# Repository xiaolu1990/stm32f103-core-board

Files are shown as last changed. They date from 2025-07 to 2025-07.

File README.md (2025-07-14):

## What is this?

This is a customized development board for STM32F103C8T6 Microcontroller. It can be powered and communicated to PC using the USB-C cable in USB 2.0 highspeed. The small size also allows to fit nicely either on a breadboard or as a module on your pcb.

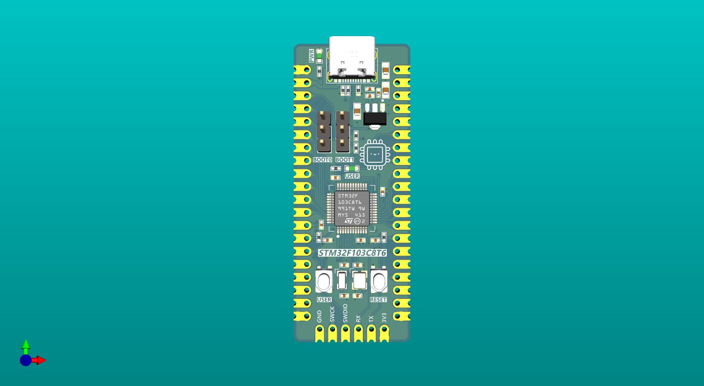
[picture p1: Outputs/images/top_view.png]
top view

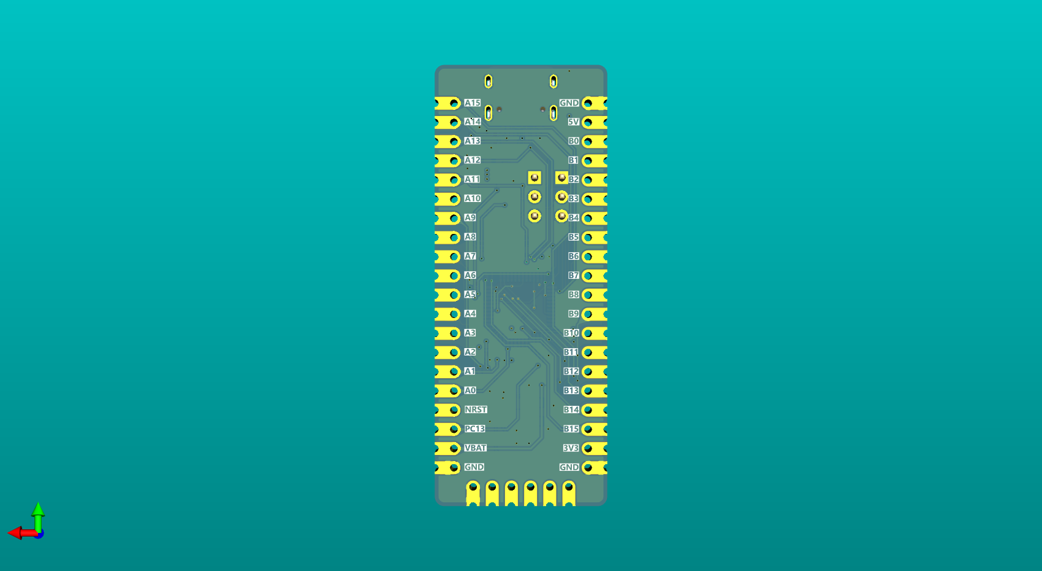
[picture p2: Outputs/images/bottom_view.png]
bottom view


## How to open the project?

Use Kicad 9.0+ versions to open the project.

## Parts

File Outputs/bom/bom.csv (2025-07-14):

Reference | Qty | Value | MPN | Manufacturer | Description
C2,C4,C7 | 3 | 4.7uF | GRM188R61E475KE11D | Murata Electronics | CAP CER 4.7UF 25V X5R 0603
C3,C5,C6,C13,C14,C15,C16,C17,C18 | 9 | 0.1uF | GRM155R71C104KA88J | Murata Electronics | CAP CER 0.1UF 16V X7R 0402
C9,C10,C11,C12 | 4 | 20pF | GRM1555C1H200JA01D | Murata Electronics | CAP CER 20PF 50V C0G/NP0 0402
CN1 | 1 | USB4105-GF-A | USB4105-GF-A | GCT | USB2.0 TYP C
J1,J2 | 2 | Conn_01x03_Pin |  |  | Generic connector, single row, 01x03, script generated
J3 | 1 | SWD |  |  | Generic connector, single row, 01x06, script generated
J4,J5 | 2 | Conn_01x20 |  |  | Generic connector, single row, 01x20, script generated (kicad-library-utils/schlib/autogen/connector/)
LED1 | 1 | 150060VS75000 | 150060VS75000 | Würth Elektronik | LED GREEN CLEAR 0603 SMD
LED2 | 1 | 150060YS75000 | 150060YS75000 | Würth Elektronik | LED YELLOW CLEAR 0603 SMD
R1 | 1 | 1K5 | RC0402JR-071K5L | YAGEO | RES 1.5K OHM 5% 1/16W 0402
R2,R8 | 2 | 1K | RC0402JR-071KL | YAGEO | RES 1K OHM 5% 1/16W 0402
R3,R4,R9,R10 | 4 | 10K | RC0402JR-0710KL | YAGEO | RES 10K OHM 5% 1/16W 0402
R5,R6 | 2 | 5K1 | RC0402FR-075K1L | YAGEO | RES 5.1K OHM 1% 1/16W 0402
SW1,SW2 | 2 | PTS810 | PTS810SJM250SMTR LFS | C&K | SWITCH TACTILE SPST 4 PIN
U1 | 1 | AMS1117-3.3V | AMS1117-3.3V | MSKSEMI | IC REG LIN 3.3V 1A SOT-89
U2 | 1 | STM32F103C8T6 | STM32F103C8T6 | STMicroelectronics | ARM® Cortex®-M3 STM32F1 Microcontroller IC 32-Bit Single-Core 72MHz 64KB (64K x 8) FLASH
X1 | 1 | 8 MHz | ECS-80-12-33-JGN-TR | ECS | CRYSTAL 8.0000MHZ 12PF SMD
X2 | 1 | 32.768 kHz | ECS-.327-12.5-34B-TR | ECS | CRYSTAL 32.7680KHZ 12.5PF SMD

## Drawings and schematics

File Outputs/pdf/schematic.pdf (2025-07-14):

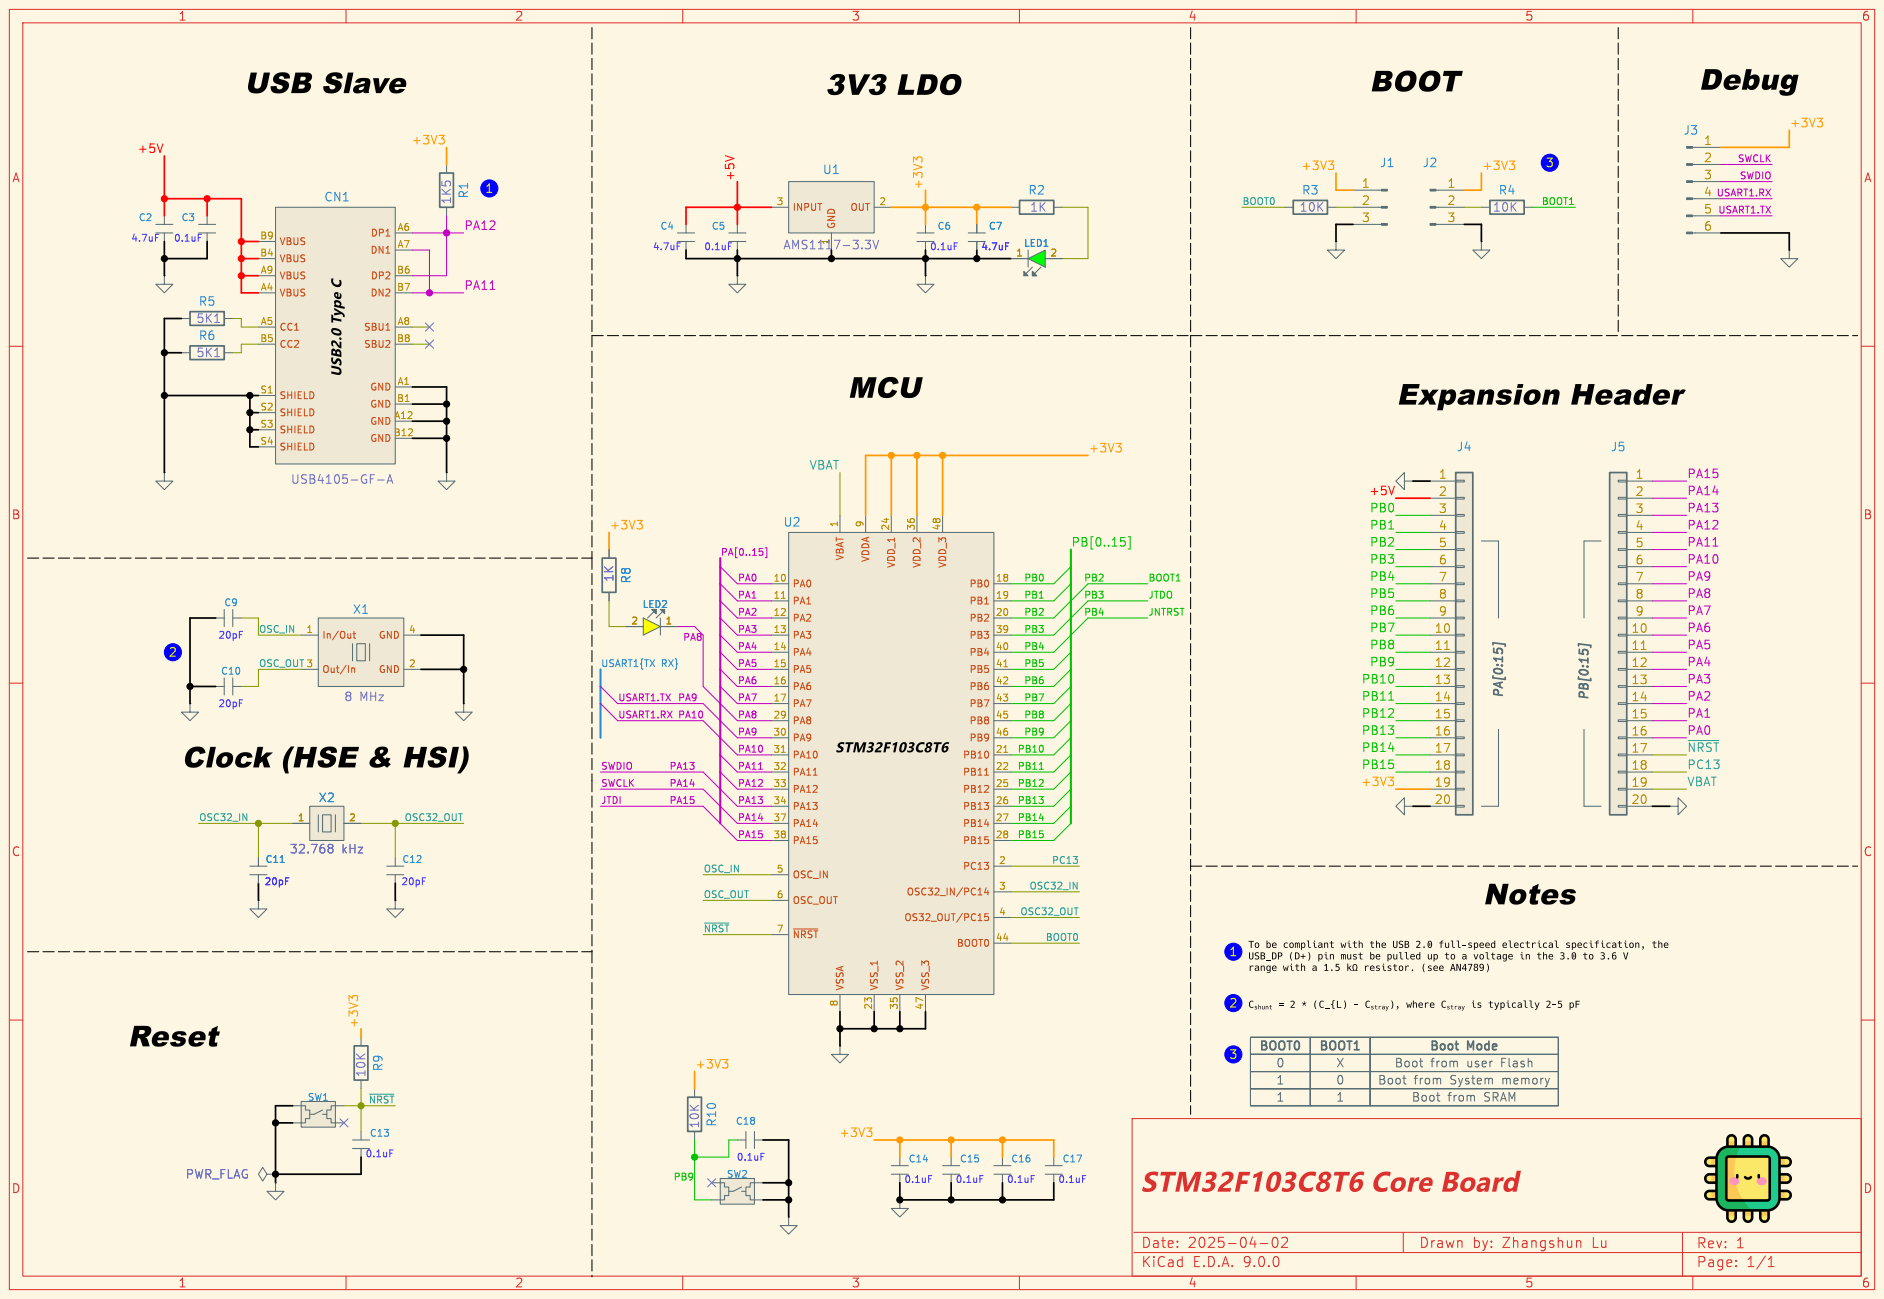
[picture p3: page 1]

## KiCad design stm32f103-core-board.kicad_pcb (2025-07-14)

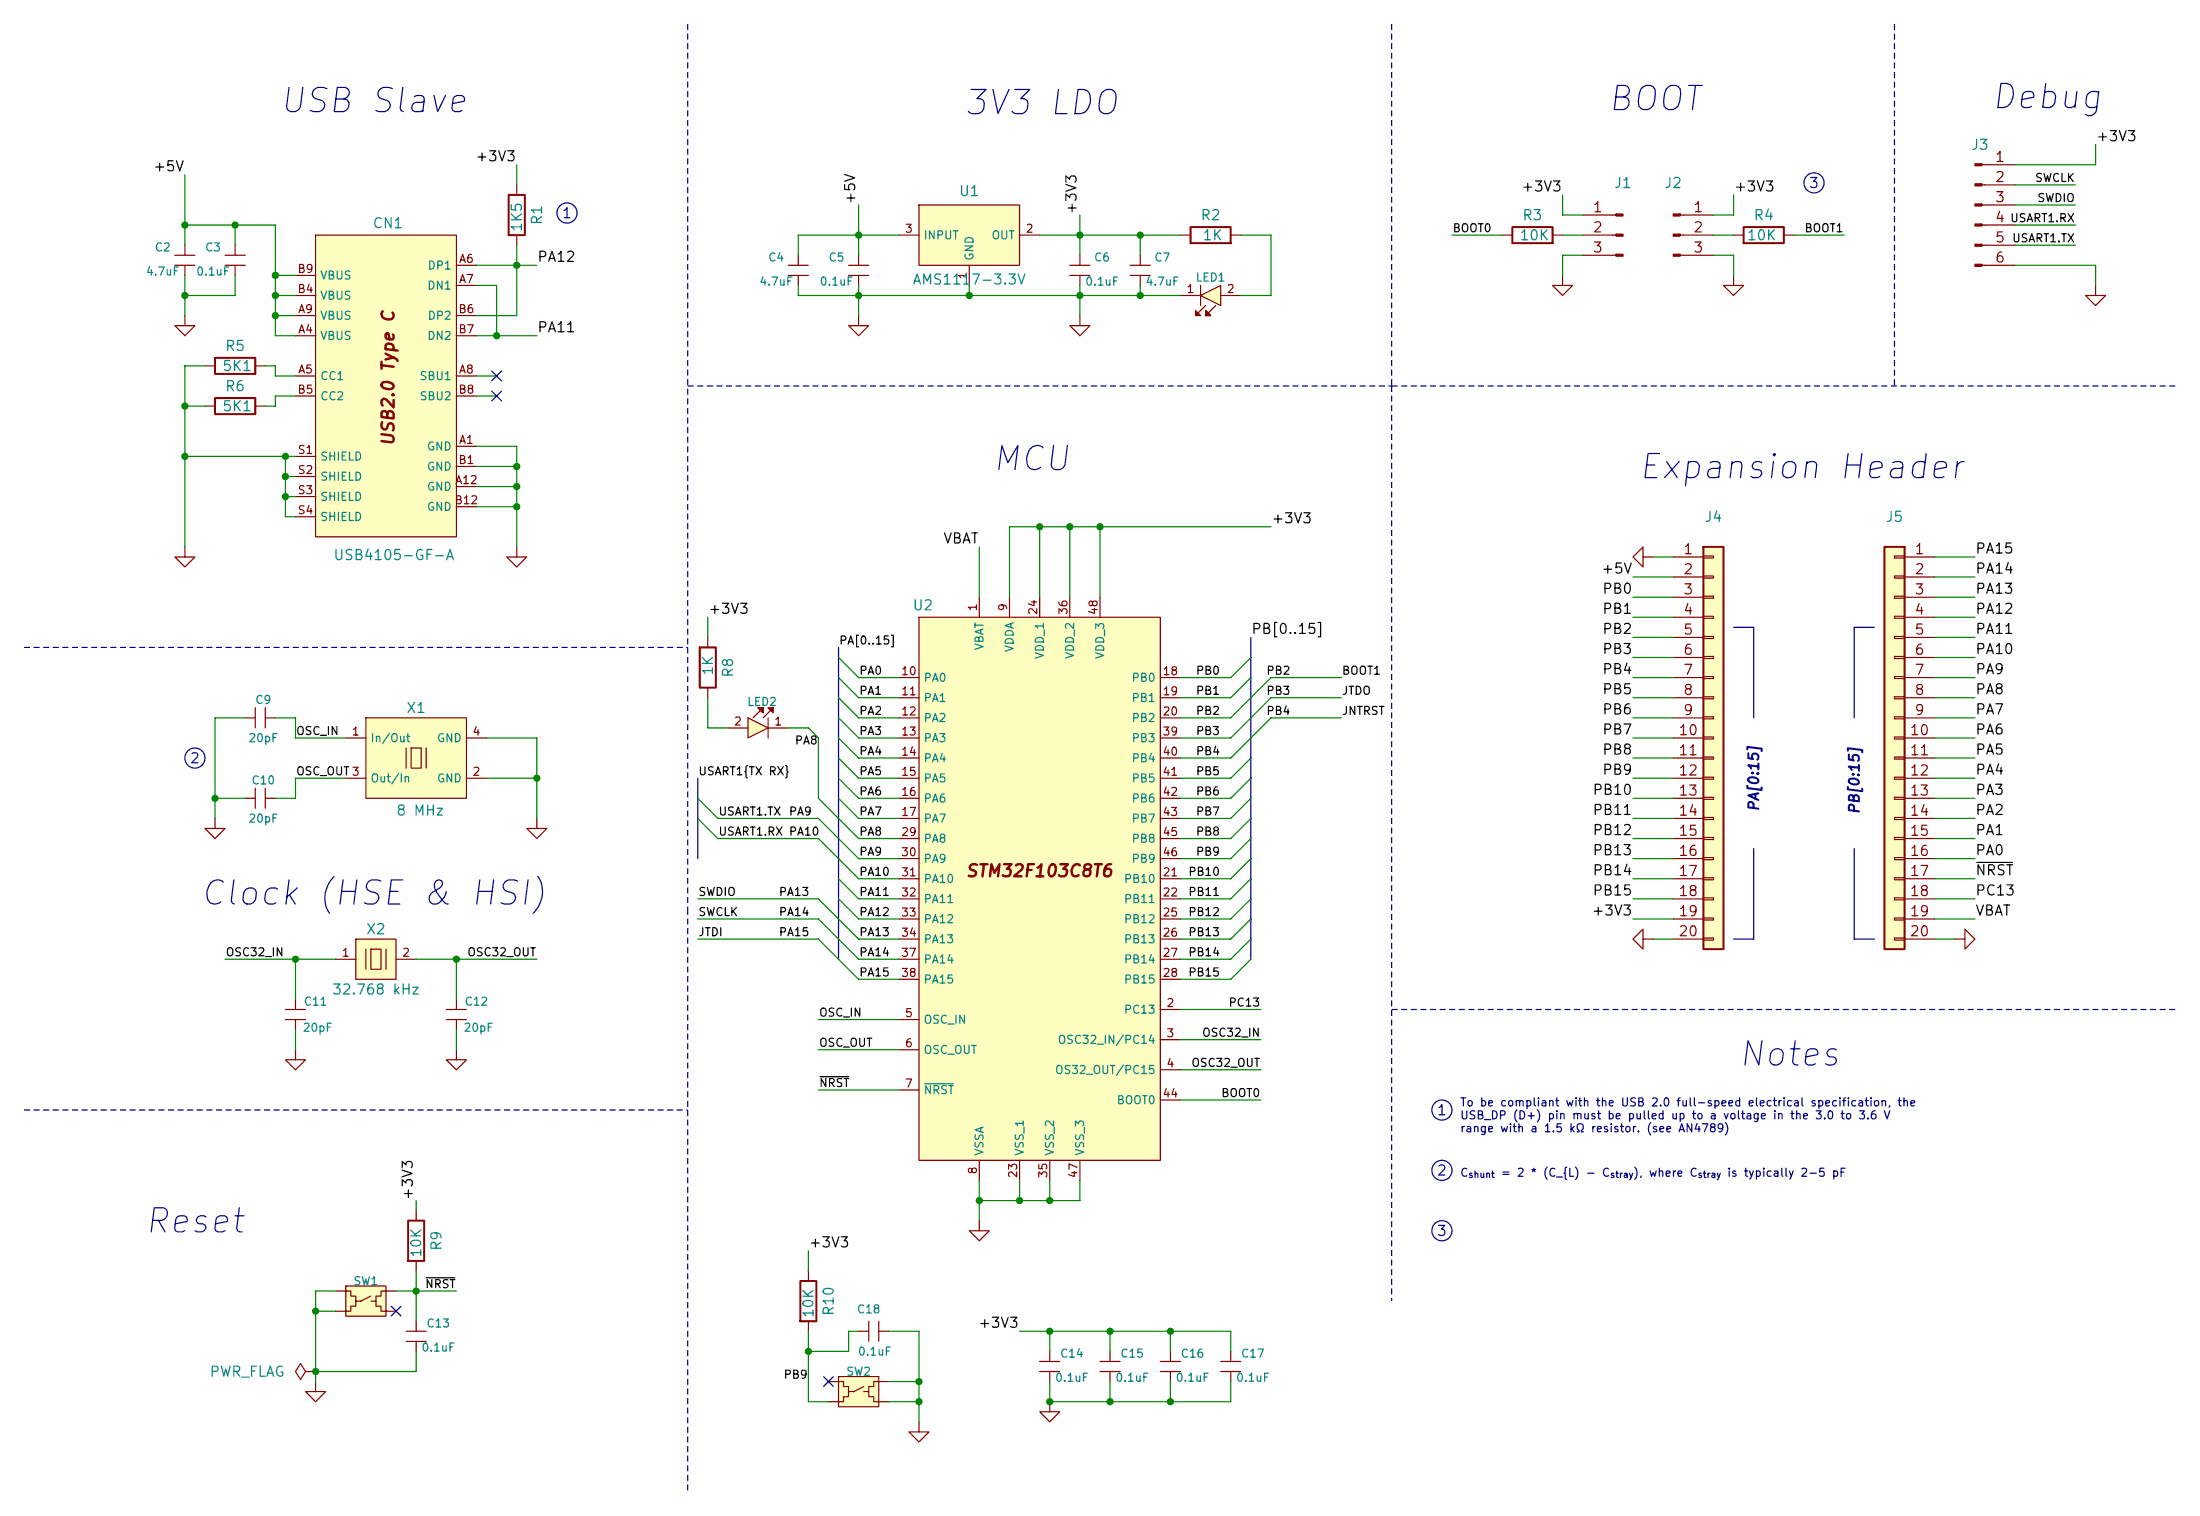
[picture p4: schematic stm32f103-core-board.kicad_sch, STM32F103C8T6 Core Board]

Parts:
C2, C4, C7: 4.7uF; C_SMD_0603; MPN GRM188R61E475KE11D
C3, C5, C6, C13, C14, C15, C16, C17, C18: 0.1uF; C_SMD_0402; MPN GRM155R71C104KA88J
C9, C10, C11, C12: 20pF; C_SMD_0402; MPN GRM1555C1H200JA01D
CN1: USB4105-GF-A; MPN USB4105-GF-A
J1, J2: Conn_01x03_Pin; PinHeader_1x03_P2.54mm_Vertical
J3: SWD; Castellated_PinHeader_1x6_2.54mm
J4, J5: Conn_01x20; Castellated_PinHeader_1x20_2.54mm
LED1: 150060VS75000; LED_SMD_0603; MPN 150060VS75000
LED2: 150060YS75000; LED_SMD_0603; MPN 150060YS75000
R1: 1K5; R_SMD_0402; MPN RC0402JR-071K5L
R2, R8: 1K; R_SMD_0402; MPN RC0402JR-071KL
R3, R4, R9, R10: 10K; R_SMD_0402; MPN RC0402JR-0710KL
R5, R6: 5K1; R_SMD_0402; MPN RC0402FR-075K1L
SW1, SW2: PTS810; SW_PTS810; MPN PTS810SJM250SMTR LFS
U1: AMS1117-3.3V; MPN AMS1117-3.3V
U2: STM32F103C8T6; MPN STM32F103C8T6
X1: 8 MHz; ECX-32; MPN ECS-80-12-33-JGN-TR
X2: 32.768 kHz; ECX-31B; MPN ECS-.327-12.5-34B-TR

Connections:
/+3V3: C6.2, C7.2, C14.2, C15.2, C16.2, C17.2, J1.1, J2.1, J3.1, J4.19, R1.1, R2.1, R8.2, R9.1, R10.1, U1.2 (OUT), U2.9 (VDDA), U2.24 (VDD_1), U2.36 (VDD_2), U2.48 (VDD_3)
/+5V: C2.2, C3.2, C4.2, C5.2, CN1.A4 (VBUS), CN1.A9 (VBUS), CN1.B4 (VBUS), CN1.B9 (VBUS), J4.2, U1.3 (INPUT)
/BOOT0: R3.1, U2.44 (BOOT0)
/OSC32_IN: C11.2, U2.3 (OSC32_IN/PC14), X2.1 (In/Out)
/OSC32_OUT: C12.2, U2.4 (OS32_OUT/PC15), X2.2 (Out/In)
/OSC_IN: C9.2, U2.5 (OSC_IN), X1.1 (In/Out)
/OSC_OUT: C10.2, U2.6 (OSC_OUT), X1.3 (Out/In)
/PA0: J5.16, U2.10 (PA0)
/PA1: J5.15, U2.11 (PA1)
/PA2: J5.14, U2.12 (PA2)
/PA3: J5.13, U2.13 (PA3)
/PA4: J5.12, U2.14 (PA4)
/PA5: J5.11, U2.15 (PA5)
/PA6: J5.10, U2.16 (PA6)
/PA7: J5.9, U2.17 (PA7)
/PA8: J5.8, LED2.1 (K), U2.29 (PA8)
/PA11: CN1.A7 (DN1), CN1.B7 (DN2), J5.5, U2.32 (PA11)
/PA12: CN1.A6 (DP1), CN1.B6 (DP2), J5.4, R1.2, U2.33 (PA12)
/PA13: J3.3, J5.3, U2.34 (PA13)
/PA14: J3.2, J5.2, U2.37 (PA14)
/PA15: J5.1, U2.38 (PA15)
/PB0: J4.3, U2.18 (PB0)
/PB1: J4.4, U2.19 (PB1)
/PB2: J4.5, R4.1, U2.20 (PB2)
/PB3: J4.6, U2.39 (PB3)
/PB4: J4.7, U2.40 (PB4)
/PB5: J4.8, U2.41 (PB5)
/PB6: J4.9, U2.42 (PB6)
/PB7: J4.10, U2.43 (PB7)
/PB8: J4.11, U2.45 (PB8)
/PB9: C18.2, J4.12, R10.2, SW2.2, U2.46 (PB9)
/PB10: J4.13, U2.21 (PB10)
/PB11: J4.14, U2.22 (PB11)
/PB12: J4.15, U2.25 (PB12)
/PB13: J4.16, U2.26 (PB13)
/PB14: J4.17, U2.27 (PB14)
/PB15: J4.18, U2.28 (PB15)
/PC13: J5.18, U2.2 (PC13)
/USART1.RX: J3.4, J5.6, U2.31 (PA10)
/USART1.TX: J3.5, J5.7, U2.30 (PA9)
/VBAT: J5.19, U2.1 (VBAT)
/~NRST: C13.2, J5.17, R9.2, SW1.4, U2.7 (~NRST)
GND: C2.1, C3.1, C4.1, C5.1, C6.1, C7.1, C9.1, C10.1, C11.1, C12.1, C13.1, C14.1, C15.1, C16.1, C17.1, C18.1, CN1.A1 (GND), CN1.A12 (GND), CN1.B1 (GND), CN1.B12 (GND), CN1.S1 (SHIELD), CN1.S2 (SHIELD), CN1.S3 (SHIELD), CN1.S4 (SHIELD), J1.3, J2.3, J3.6, J4.1, J4.20, J5.20, LED1.1 (K), R5.1, R6.1, SW1.1, SW1.2, SW2.3, SW2.4, U1.1 (GND), U2.8 (VSSA), U2.23 (VSS_1), U2.35 (VSS_2), U2.47 (VSS_3), X1.2 (GND), X1.4 (GND)
unnamed: CN1.A5 (CC1), R5.2
unnamed: CN1.B5 (CC2), R6.2
unnamed: J1.2, R3.2
unnamed: J2.2, R4.2
unnamed: LED1.2 (A), R2.2
unnamed: LED2.2 (A), R8.1

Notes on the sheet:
PA[0:15]
Notes
USB Slave
3V3 LDO
Debug
Expansion Header
MCU
BOOT
Reset
Clock (HSE & HSI)
PB[0:15]
C_{shunt} = 2 * (C_{L) - C_{stray}), where C_{stray} is typically 2-5 pF
To be compliant with the USB 2.0 full-speed electrical specification, the USB_DP (D+) pin must be pulled up to a voltage in the 3.0 to 3.6 V range with a 1.5 kΩ resistor. (see AN4789)

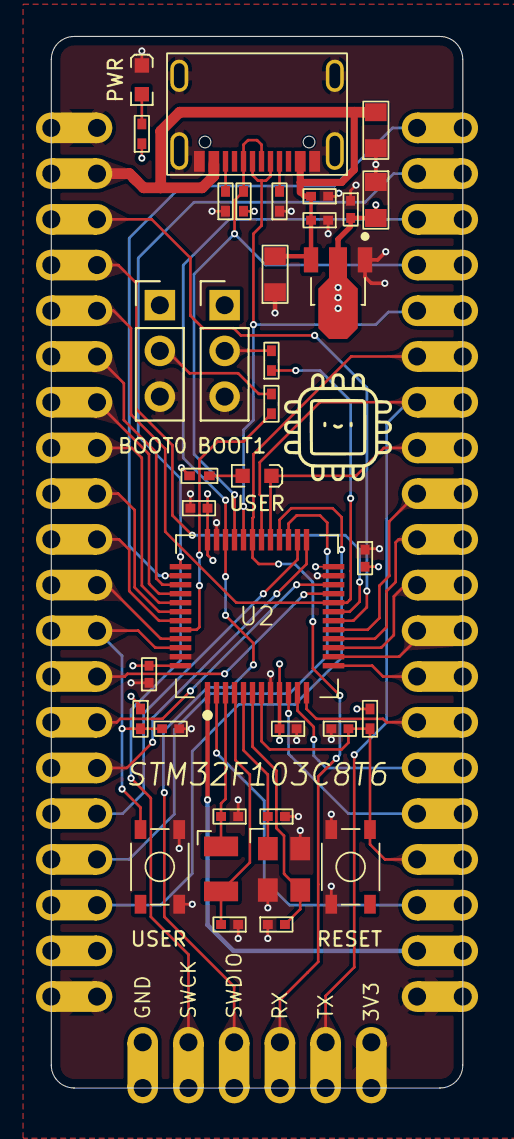
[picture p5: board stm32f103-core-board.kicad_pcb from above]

Board: 4 copper layers, 22.9 x 58.4 mm, 39 parts (0 on the bottom side), 49 nets.
